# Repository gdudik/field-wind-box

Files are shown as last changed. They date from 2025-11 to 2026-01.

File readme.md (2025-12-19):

# Programming the main controller board (USB-PD controller setup)

I am using a cheapo CH134A programmer board with an alligator clamp for SOIC-8. Example: https://a.co/d/9YnwEmc. This unit needed to be modded per the included instructions to work with an EEPROM chip running at 3.3v.

Binary file `USB_C_PD_controller.bin` was built using the TI Application Customization Tool at https://www.ti.com/tool/USBCPD-APPLICATION-CUSTOMIZATION-TOOL.

Choices used:
- Device Type: TPS25751
- Choose TPS 25751S under _Are you a 5V @ 3A power source (provider) only?_
- Highest supported USB Speed: USB 2
- Preferred data role: Device/Upstream Facing Port
- Support BC 1.2? No
- Liquid detection on Type C Connector? No
- Vendor ID and Desired Product ID: TI Vendor ID/0x0000 Product ID

After downloading the bin file from the tool, I used IMS_Prog which is a tool for Mac that will interface with the CH134A. On PC there are other tools, but you'll have to Google. IMS_Prog supposedly also works on Linux.

# Wiring

## 4-Pin Header to XLR
| 4 Pin Header | Wire Color  | Function  | XLR Pin Num  |
|---|---|---|---|
| 1  | Red  | Wind Gauge +12v  | 2  |
|  2 | Black  | Wind Gauge Pwr GND  | Shell  |
| 3  | Green  | Data RX from WG  | 3  |
|  4 |  White | Data GND  | 1  |

## 3-Pin Header to LP16 for RS232
| 3 Pin Header | Wire Color  | Function  | LP16 Pin Num  |
|---|---|---|---|
| 1  | Orange  | RXI  | 2  |
|  2 | White  | Data GND  | 3  |
| 3  | Blue  | TXO  | 1  |

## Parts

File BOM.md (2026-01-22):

Case: Apache 1800 from HF https://www.harborfreight.com/1800-weatherproof-protective-case-small-black-64550.html $12.99
Battery: LiFePO4 12V 10AH ~$36.00
Charger: 12V 3A LiFePO4 charger ~18.00

Board $16
2x FT232RL $4.35 ea
XLR Port $4.91
Neutrik SCDF Plug $1.91
3-Pin CNLINKO serial port $7.33
USB-C CNLINKO port $5.06
USB-C CNLINKO cable $9.31
PowerCon port $5.24
Powercon plug $5.71
3.5" long 1/4-20 bolts qty 2 $.47 ea
1/4-20" nylock nuts qty 2 $.14 ea
Metal hold down strap $1.94
Hirose cable $7.50
standoffs x4 $.28 ea
o-rings for board mount x4 $.14
Right-angle USB cable $2.86
Orange power plug $4
Power button $8.38

3-wire harness for serial, 11"
4-wire harness for WG, 14"

battery board?
led caps

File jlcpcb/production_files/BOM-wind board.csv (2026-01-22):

Comment | Designator | Footprint | LCSC | Quantity
0 | R1 | R_0402_1005Metric | C17168 | 1
0.01uF | C51,C52,C53,C54 | C_0402_1005Metric | C15195 | 4
100K | R9 | R_0402_1005Metric | C25741 | 1
100nF | C11,C15,C16,C19,C20,C27,C31,C32,C35,C36,C41,C42,C50,C6,C8,C9 | C_0402_1005Metric | C1525 | 16
100uF / 10V | C57,C58 | C_1206_3216Metric | C7432784 | 2
10K | R10,R2,R8 | R_0402_1005Metric | C25744 | 3
10uF | C1,C25,C26,C3,C43,C44,C49 | C_0402_1005Metric | C15525 | 7
10uF / 10V | C55,C56 | C_0603_1608Metric | C19702 | 2
12MHz | Y1 | Crystal_SMD_3225-4Pin_3.2x2.5mm | C9002 | 1
1N4148WS | D5 | D_SOD-323 | C2128 | 1
1uF | C2,C45,C46 | C_0402_1005Metric | C52923 | 3
20K | R11 | R_0402_1005Metric | C25765 | 1
220K | R13 | R_0603_1608Metric | C22961 | 1
22uF | C28,C29,C30 | C_0603_1608Metric | C59461 | 3
30K | R12,R14 | R_0603_1608Metric | C22984 | 2
330pF | C47,C48 | C_0603_1608Metric | C1664 | 2
4.7uF | C33,C7 | C_0603_1608Metric | C19666 | 2
4.7uF | C17 | C_0402_1005Metric | C23733 | 1
4.7uF 25V | C24 | C_0805_2012Metric | C1779 | 1
470 | R18,R19,R3,R4,R5,R6,R7 | R_0402_1005Metric | C25117 | 7
470nF | C10,C12,C13,C18,C21,C22,C34,C37,C38 | C_0603_1608Metric | C1623 | 9
47pF | C14,C23,C39,C40 | C_0402_1005Metric | C1567 | 4
47pF | C4,C5 | C_0603_1608Metric | C1671 | 2
AONR21321 | Q1 | TRANS_AONR21321 | C541711 | 1
AT24C512C-SSHM | U10 | SOIC-8_3.9x4.9mm_P1.27mm | C54668 | 1
CH334R | U1 | QSOP-16_3.9x4.9mm_P0.635mm | C4154405 | 1
HCB3216KF-601T30 | FB1 | C_1206_3216Metric | C357023 | 1
LED | D15,D2,D4,D7 | LED_0603_1608Metric | C2286 | 4
LED | D1,D3,D8 | LED_0603_1608Metric | C2290 | 3
MMSZ18T1G | D6 | D_SOD-123 | C40707 | 1
PTPS25751SRSMR | U9 | RSM0032B-IPC_A | C22460852 | 1
SM15-02HTG | D10,D11,D12,D13,D14,D9 | SM0502HTG | C1975435 | 6
SPM6530T-2R2M | L1 | IND_SPM6530T-2R2M | C76855 | 1
TPS565242 | U6 | SOT6_DRL_TEX-L | C5219270 | 1
TVS2200DRV | U12 | WSON-6-1EP_2x2mm_P0.65mm_EP1x1.6mm | C523793 | 1
USB_C_Receptacle_USB2.0_14P | J1 | USB_C_Receptacle_HRO_TYPE-C-31-M-12 | C165948 | 1
XC6206PxxxMR | U11 | SOT-23-3 | C5446 | 1
ZT3222F | U4,U5,U8 | TSSOP-20_4.4x6.5mm_P0.65mm | C19078605 | 3

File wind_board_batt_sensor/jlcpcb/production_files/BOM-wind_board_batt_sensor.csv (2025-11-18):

Comment | Designator | Footprint | LCSC | Quantity
30 | R6 | R_0805_2012Metric_Pad1.20x1.40mm_HandSolder |  | 1
10K | R9 | R_0805_2012Metric_Pad1.20x1.40mm_HandSolder |  | 1
100nF | C5 | R_0805_2012Metric_Pad1.20x1.40mm_HandSolder |  | 1
PTSM82903SISB2R | U2 | SIS0011A-MFG |  | 1
TestPoint | J_PA0 | TestPoint_Pad_4.0x4.0mm |  | 1
Batt + | J1 | MountingHole_4.3mm_M4_ISO7380_Pad_TopBottom |  | 1
26.1k | R3 | R_0805_2012Metric_Pad1.20x1.40mm_HandSolder |  | 1
LED | D5 | LED_D5.0mm |  | 1
LED | D2 | LED_D5.0mm |  | 1
LED | D1 | LED_D5.0mm |  | 1
Batt - | J2 | MountingHole_4.3mm_M4_ISO7380_Pad_TopBottom |  | 1
30 | R4 | R_0805_2012Metric_Pad1.20x1.40mm_HandSolder |  | 1
MAX17263xxTE | U1 | DFN-14-1EP_3x3mm_P0.4mm_EP1.78x2.35mm |  | 1
22uF | C2 | R_0805_2012Metric_Pad1.20x1.40mm_HandSolder |  | 1
200k - 0.1% | R2 | R_0805_2012Metric_Pad1.20x1.40mm_HandSolder |  | 1
10uF | C1 | R_0805_2012Metric_Pad1.20x1.40mm_HandSolder |  | 1
4.7uF | C6 | R_0805_2012Metric_Pad1.20x1.40mm_HandSolder |  | 1
100 nF | C3 | R_0805_2012Metric_Pad1.20x1.40mm_HandSolder |  | 1
LED | D4 | LED_D5.0mm |  | 1
30 | R5 | R_0805_2012Metric_Pad1.20x1.40mm_HandSolder |  | 1
LED | D3 | LED_D5.0mm |  | 1
10K | R11 | R_0805_2012Metric_Pad1.20x1.40mm_HandSolder |  | 1
30 | R7 | R_0805_2012Metric_Pad1.20x1.40mm_HandSolder |  | 1
10K | R10 | R_0805_2012Metric_Pad1.20x1.40mm_HandSolder |  | 1
470nF | C4 | R_0805_2012Metric_Pad1.20x1.40mm_HandSolder |  | 1
1.5M - 0.1% | R1 | R_0805_2012Metric_Pad1.20x1.40mm_HandSolder |  | 1
ATtiny402-SS | U3 | SOIC-8_3.9x4.9mm_P1.27mm |  | 1
Sys - | J4 | MountingHole_4.3mm_M4_ISO7380_Pad_TopBottom |  | 1
300k - 0.1% | R8 | R_0805_2012Metric_Pad1.20x1.40mm_HandSolder |  | 1
Sys + | J3 | MountingHole_4.3mm_M4_ISO7380_Pad_TopBottom |  | 1

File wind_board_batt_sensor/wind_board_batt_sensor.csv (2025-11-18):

Reference | Qty | Value | DNP | Exclude from BOM | Exclude from Board | Footprint | Datasheet
C1 | 1 | 10uF |  |  |  | Resistor_SMD:R_0805_2012Metric_Pad1.20x1.40mm_HandSolder | ~
C2 | 1 | 22uF |  |  |  | Resistor_SMD:R_0805_2012Metric_Pad1.20x1.40mm_HandSolder | ~
C3 | 1 | 100 nF |  |  |  | Resistor_SMD:R_0805_2012Metric_Pad1.20x1.40mm_HandSolder | ~
C4 | 1 | 470nF |  |  |  | Resistor_SMD:R_0805_2012Metric_Pad1.20x1.40mm_HandSolder | ~
C5 | 1 | 100nF |  |  |  | Resistor_SMD:R_0805_2012Metric_Pad1.20x1.40mm_HandSolder | ~
C6 | 1 | 4.7uF |  |  |  | Resistor_SMD:R_0805_2012Metric_Pad1.20x1.40mm_HandSolder | ~
D1,D2,D3,D4,D5 | 5 | LED |  |  |  | LED_THT:LED_D5.0mm | ~
J1 | 1 | Batt + |  |  |  | MountingHole:MountingHole_4.3mm_M4_ISO7380_Pad_TopBottom | ~
J2 | 1 | Batt - |  |  |  | MountingHole:MountingHole_4.3mm_M4_ISO7380_Pad_TopBottom | ~
J3 | 1 | Sys + |  |  |  | MountingHole:MountingHole_4.3mm_M4_ISO7380_Pad_TopBottom | ~
J4 | 1 | Sys - |  |  |  | MountingHole:MountingHole_4.3mm_M4_ISO7380_Pad_TopBottom | ~
J_PA0 | 1 | TestPoint |  |  |  | TestPoint:TestPoint_Pad_4.0x4.0mm | ~
R1 | 1 | 1.5M - 0.1% |  |  |  | Resistor_SMD:R_0805_2012Metric_Pad1.20x1.40mm_HandSolder | ~
R2 | 1 | 200k - 0.1% |  |  |  | Resistor_SMD:R_0805_2012Metric_Pad1.20x1.40mm_HandSolder | ~
R3 | 1 | 26.1k |  |  |  | Resistor_SMD:R_0805_2012Metric_Pad1.20x1.40mm_HandSolder | ~
R4,R5,R6,R7 | 4 | 30 |  |  |  | Resistor_SMD:R_0805_2012Metric_Pad1.20x1.40mm_HandSolder | ~
R8 | 1 | 300k - 0.1% |  |  |  | Resistor_SMD:R_0805_2012Metric_Pad1.20x1.40mm_HandSolder | ~
R9,R10,R11 | 3 | 10K |  |  |  | Resistor_SMD:R_0805_2012Metric_Pad1.20x1.40mm_HandSolder | ~
R_SENSE3 | 1 | 10m |  |  |  | Resistor_SMD:R_1206_3216Metric_Pad1.30x1.75mm_HandSolder | ~
U1 | 1 | MAX17263xxTE |  |  |  | Package_DFN_QFN:DFN-14-1EP_3x3mm_P0.4mm_EP1.78x2.35mm | https://datasheets.maximintegrated.com/en/ds/MAX17263.pdf
U2 | 1 | PTSM82903SISB2R |  |  |  | TPSM82903:SIS0011A-MFG | PTSM82903SISB2R
U3 | 1 | ATtiny402-SS |  |  |  | Package_SO:SOIC-8_3.9x4.9mm_P1.27mm | http://ww1.microchip.com/downloads/en/DeviceDoc/ATtiny202-402-AVR-MCU-with-Core-Independent-Peripherals_and-picoPower-40001969A.pdf

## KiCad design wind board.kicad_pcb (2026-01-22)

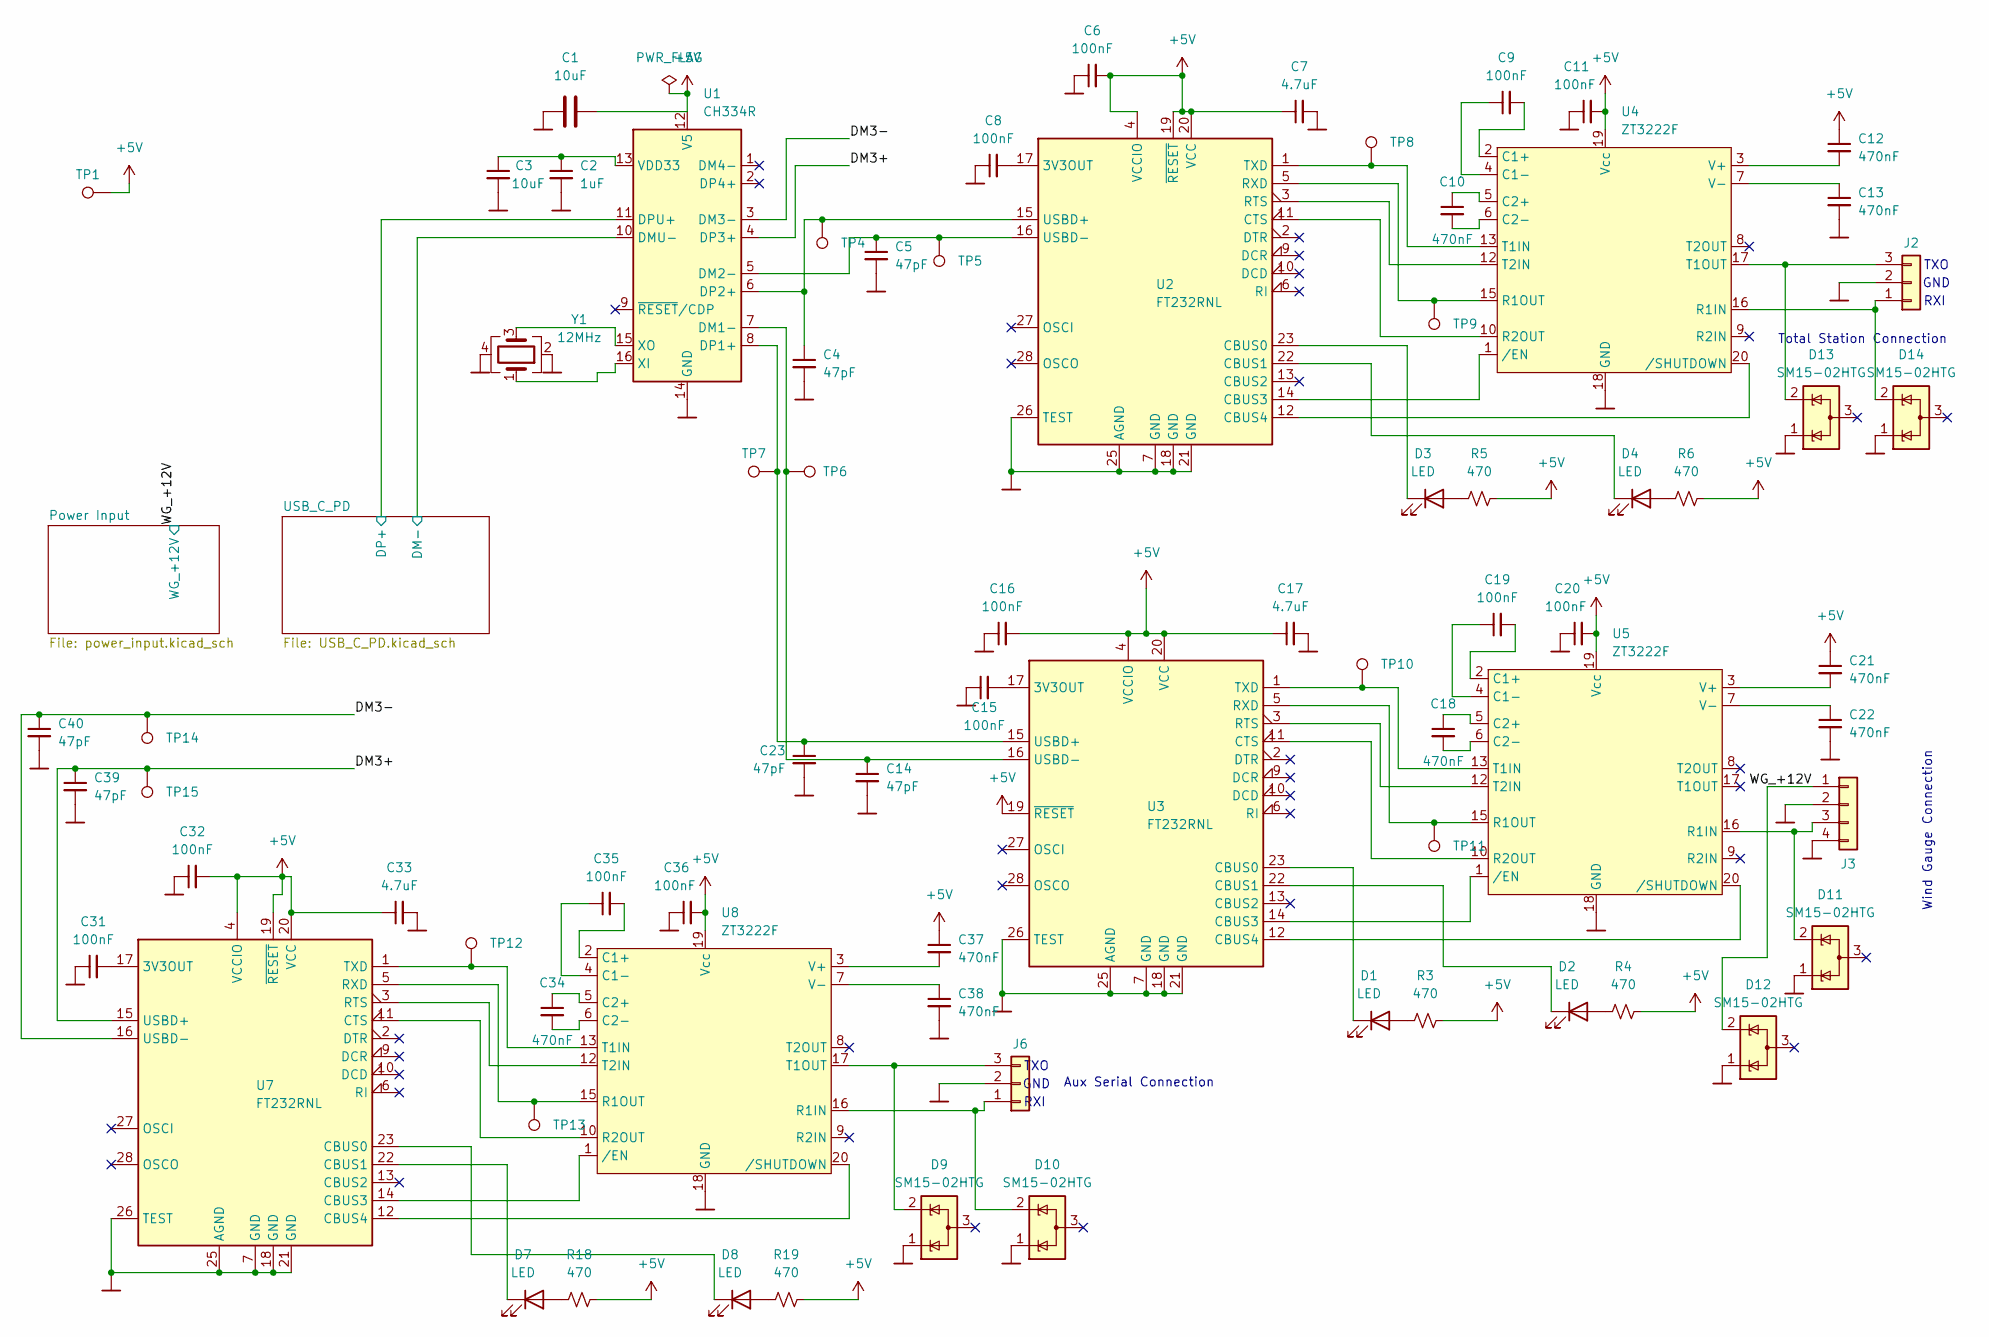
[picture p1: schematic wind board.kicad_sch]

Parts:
C1, C3: 10uF; C_0402_1005Metric
C2: 1uF; C_0402_1005Metric
C4, C5: 47pF; C_0603_1608Metric
C6, C8, C9, C11, C15, C16, C19, C20, C31, C32, C35, C36: 100nF; C_0402_1005Metric
C7, C33: 4.7uF; C_0603_1608Metric
C10, C12, C13, C18, C21, C22, C34, C37, C38: 470nF; C_0603_1608Metric
C14, C23, C39, C40: 47pF; C_0402_1005Metric
C17: 4.7uF; C_0402_1005Metric
D1, D2, D3, D4, D7, D8: LED; LED_0603_1608Metric
D9, D10, D11, D12, D13, D14: SM15-02HTG; SM0502HTG
J2, J6: Conn_01x06_MountingPin; PinHeader_1x03_P2.54mm_Horizontal
J3: Conn_01x06_MountingPin; PinHeader_1x04_P2.54mm_Horizontal
R3, R4, R5, R6, R18, R19: 470; R_0402_1005Metric
TP1, TP4, TP5, TP6, TP7, TP8, TP9, TP10, TP11, TP12, TP13, TP14, TP15: TestPoint; TestPoint_THTPad_1.0x1.0mm_Drill0.5mm
U1: CH334R; QSOP-16_3.9x4.9mm_P0.635mm
U2, U3, U7: FT232RNL; SSOP-28_5.3x10.2mm_P0.65mm
U4, U5, U8: ZT3222F; TSSOP-20_4.4x6.5mm_P0.65mm
Y1: 12MHz; Crystal_SMD_3225-4Pin_3.2x2.5mm

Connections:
+5V: C1.2, C6.2, C7.1, C11.2, C12.1, C16.2, C17.1, C20.2, C21.1, C32.2, C33.1, C36.2, C37.1, R3.2, R4.2, R5.2, R6.2, R18.2, R19.2, TP1.1, U1.12 (V5), U2.4 (VCCIO), U2.19 (~RESET), U2.20 (VCC), U3.4 (VCCIO), U3.19 (~RESET), U3.20 (VCC), U4.19 (Vcc), U5.19 (Vcc), U7.4 (VCCIO), U7.19 (~RESET), U7.20 (VCC), U8.19 (Vcc); also elsewhere on the board
/DM3+: C39.1, TP15.1, U1.4 (DP3+), U7.15 (USBD+)
/DM3-: C40.1, TP14.1, U1.3 (DM3-), U7.16 (USBD-)
/USB_C_PD/DM-: U1.10 (DMU-); also elsewhere on the board
/USB_C_PD/DP+: U1.11 (DPU+); also elsewhere on the board
/WG_+12V: D12.2 (K), J3.1; also elsewhere on the board
unnamed: D1.2 (A), R3.1
unnamed: D1.1 (K), U3.23 (CBUS0)
unnamed: D2.2 (A), R4.1
unnamed: D2.1 (K), U3.22 (CBUS1)
unnamed: D3.2 (A), R5.1
unnamed: D3.1 (K), U2.23 (CBUS0)
unnamed: D4.2 (A), R6.1
unnamed: D4.1 (K), U2.22 (CBUS1)
unnamed: D7.2 (A), R18.1
unnamed: D7.1 (K), U7.22 (CBUS1)
unnamed: D8.2 (A), R19.1
unnamed: D8.1 (K), U7.23 (CBUS0)
unnamed: D14.2 (K), J2.1, U4.16 (R1IN)
unnamed: D13.2 (K), J2.3, U4.17 (T1OUT)
unnamed: D11.2 (K), J3.3, U5.16 (R1IN)
unnamed: D10.2 (K), J6.1, U8.16 (R1IN)
unnamed: D9.2 (K), J6.3, U8.17 (T1OUT)
unnamed: C14.1, TP6.1, U1.7 (DM1-), U3.16 (USBD-)
unnamed: C5.1, TP5.1, U1.5 (DM2-), U2.16 (USBD-)
unnamed: C23.1, TP7.1, U1.8 (DP1+), U3.15 (USBD+)
unnamed: C4.1, TP4.1, U1.6 (DP2+), U2.15 (USBD+)
unnamed: C2.1, C3.1, U1.13 (VDD33)
unnamed: U1.16 (XI), Y1.1
unnamed: U1.15 (XO), Y1.3
unnamed: C8.2, U2.17 (3V3OUT)
unnamed: U2.14 (CBUS3), U4.1 (/EN)
unnamed: U2.12 (CBUS4), U4.20 (/SHUTDOWN)
unnamed: U2.11 (CTS), U4.10 (R2OUT)
unnamed: U2.3 (RTS), U4.12 (T2IN)
unnamed: TP9.1, U2.5 (RXD), U4.15 (R1OUT)
unnamed: TP8.1, U2.1 (TXD), U4.13 (T1IN)
unnamed: C15.2, U3.17 (3V3OUT)
unnamed: U3.14 (CBUS3), U5.1 (/EN)
unnamed: U3.12 (CBUS4), U5.20 (/SHUTDOWN)
unnamed: U3.11 (CTS), U5.10 (R2OUT)
unnamed: U3.3 (RTS), U5.12 (T2IN)
unnamed: TP11.1, U3.5 (RXD), U5.15 (R1OUT)
unnamed: TP10.1, U3.1 (TXD), U5.13 (T1IN)
unnamed: C9.2, U4.2 (C1+)
unnamed: C9.1, U4.4 (C1-)
unnamed: C10.1, U4.5 (C2+)
unnamed: C10.2, U4.6 (C2-)
unnamed: C12.2, U4.3 (V+)
unnamed: C13.1, U4.7 (V-)
unnamed: C19.2, U5.2 (C1+)
unnamed: C19.1, U5.4 (C1-)
unnamed: C18.1, U5.5 (C2+)
unnamed: C18.2, U5.6 (C2-)
unnamed: C21.2, U5.3 (V+)
unnamed: C22.1, U5.7 (V-)
unnamed: C31.2, U7.17 (3V3OUT)
unnamed: U7.14 (CBUS3), U8.1 (/EN)
unnamed: U7.12 (CBUS4), U8.20 (/SHUTDOWN)
unnamed: U7.11 (CTS), U8.10 (R2OUT)
unnamed: U7.3 (RTS), U8.12 (T2IN)
unnamed: TP13.1, U7.5 (RXD), U8.15 (R1OUT)
unnamed: TP12.1, U7.1 (TXD), U8.13 (T1IN)
unnamed: C35.2, U8.2 (C1+)
unnamed: C35.1, U8.4 (C1-)
unnamed: C34.1, U8.5 (C2+)
unnamed: C34.2, U8.6 (C2-)
unnamed: C37.2, U8.3 (V+)
unnamed: C38.1, U8.7 (V-)
~: C1.1, C2.2, C3.2, C4.2, C5.2, C6.1, C7.2, C8.1, C11.1, C13.2, C14.2, C15.1, C16.1, C17.2, C20.1, C22.2, C23.2, C31.1, C32.1, C33.2, C36.1, C38.2, C39.2, C40.2, D9.1 (K), D10.1 (K), D11.1 (K), D12.1 (K), D13.1 (K), D14.1 (K), J2.2, J3.2, J3.4, J6.2, U1.14 (GND), U2.7 (GND), U2.18 (GND), U2.21 (GND), U2.25 (AGND), U2.26 (TEST), U3.7 (GND), U3.18 (GND), U3.21 (GND), U3.25 (AGND), U3.26 (TEST), U4.18 (GND), U5.18 (GND), U7.7 (GND), U7.18 (GND), U7.21 (GND), U7.25 (AGND), U7.26 (TEST), U8.18 (GND), Y1.2, Y1.4; also elsewhere on the board

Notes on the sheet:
Total Station Connection
Aux Serial Connection
GND
TXO
Wind Gauge Connection
RXI

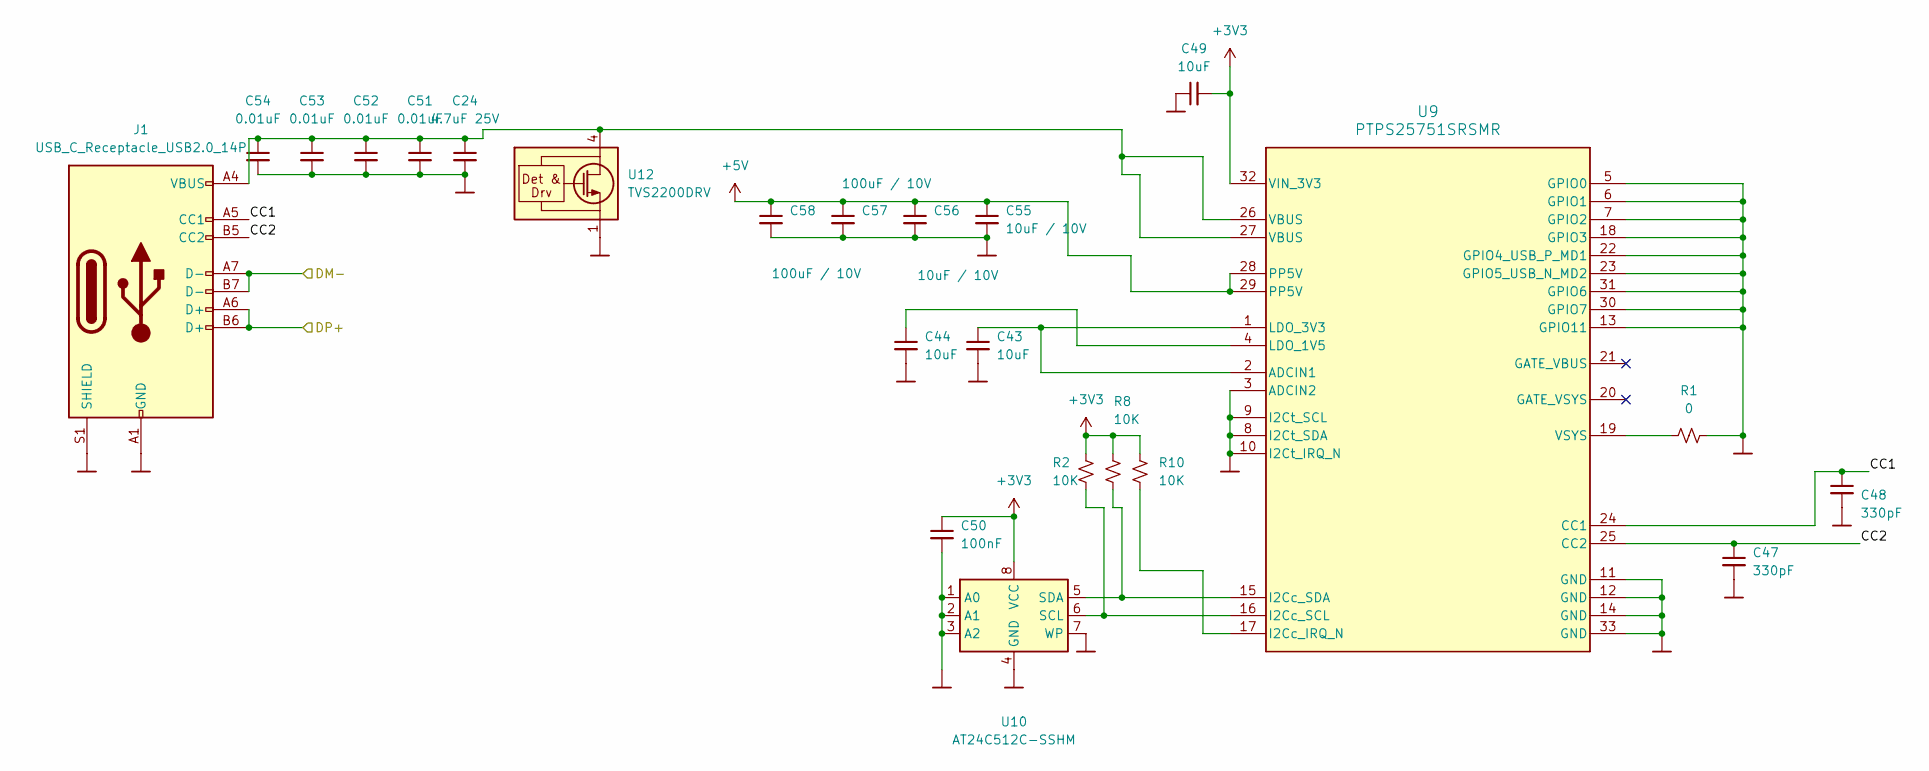
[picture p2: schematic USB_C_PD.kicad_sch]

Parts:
C24: 4.7uF 25V; C_0805_2012Metric
C43, C44, C49: 10uF; C_0402_1005Metric
C47, C48: 330pF; C_0603_1608Metric
C50: 100nF; C_0402_1005Metric
C51, C52, C53, C54: 0.01uF; C_0402_1005Metric
C55, C56: 10uF / 10V; C_0603_1608Metric
C57, C58: 100uF / 10V; C_1206_3216Metric
J1: USB_C_Receptacle_USB2.0_14P; USB_C_Receptacle_HRO_TYPE-C-31-M-12
R1: 0; R_0402_1005Metric
R2, R8, R10: 10K; R_0402_1005Metric
U9: PTPS25751SRSMR; RSM0032B-IPC_A
U10: AT24C512C-SSHM; SOIC-8_3.9x4.9mm_P1.27mm
U12: TVS2200DRV; WSON-6-1EP_2x2mm_P0.65mm_EP1x1.6mm

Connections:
+3V3: C49.2, C50.1, R2.1, R8.1, R10.1, U9.32 (VIN_3V3), U10.8 (VCC); also elsewhere on the board
+5V: C55.1, C56.1, C57.1, C58.1, U9.28 (PP5V), U9.29 (PP5V); also elsewhere on the board
/USB_C_PD/CC1: C48.1, J1.A5 (CC1), U9.24 (CC1)
/USB_C_PD/CC2: C47.1, J1.B5 (CC2), U9.25 (CC2)
/USB_C_PD/DM-: J1.A7 (D-), J1.B7 (D-); also elsewhere on the board
/USB_C_PD/DP+: J1.A6 (D+), J1.B6 (D+); also elsewhere on the board
unnamed: C24.1, C51.1, C52.1, C53.1, C54.1, J1.A4 (VBUS), J1.A9 (VBUS), J1.B4 (VBUS), J1.B9 (VBUS), U9.26 (VBUS), U9.27 (VBUS), U12.4 (IN), U12.5 (IN), U12.6 (IN)
unnamed: C43.1, U9.1 (LDO_3V3), U9.2 (ADCIN1)
unnamed: R10.2, U9.17 (I2Cc_IRQ_N)
unnamed: C44.1, U9.4 (LDO_1V5)
unnamed: R1.2, U9.19 (VSYS)
unnamed: R2.2, U9.16 (I2Cc_SCL), U10.6 (SCL)
unnamed: R8.2, U9.15 (I2Cc_SDA), U10.5 (SDA)
~: C24.2, C43.2, C44.2, C47.2, C48.2, C49.1, C50.2, C51.2, C52.2, C53.2, C54.2, C55.2, C56.2, C57.2, C58.2, J1.A1 (GND), J1.A12 (GND), J1.B1 (GND), J1.B12 (GND), J1.S1 (SHIELD), R1.1, U9.3 (ADCIN2), U9.5 (GPIO0), U9.6 (GPIO1), U9.7 (GPIO2), U9.8 (I2Ct_SDA), U9.9 (I2Ct_SCL), U9.10 (I2Ct_IRQ_N), U9.11 (GND), U9.12 (GND), U9.13 (GPIO11), U9.14 (GND), U9.18 (GPIO3), U9.22 (GPIO4_USB_P_MD1), U9.23 (GPIO5_USB_N_MD2), U9.30 (GPIO7), U9.31 (GPIO6), U9.33 (GND), U10.1 (A0), U10.2 (A1), U10.3 (A2), U10.4 (GND), U10.7 (WP), U12.1 (GND), U12.2 (GND), U12.3 (GND), U12.7 (GND); also elsewhere on the board

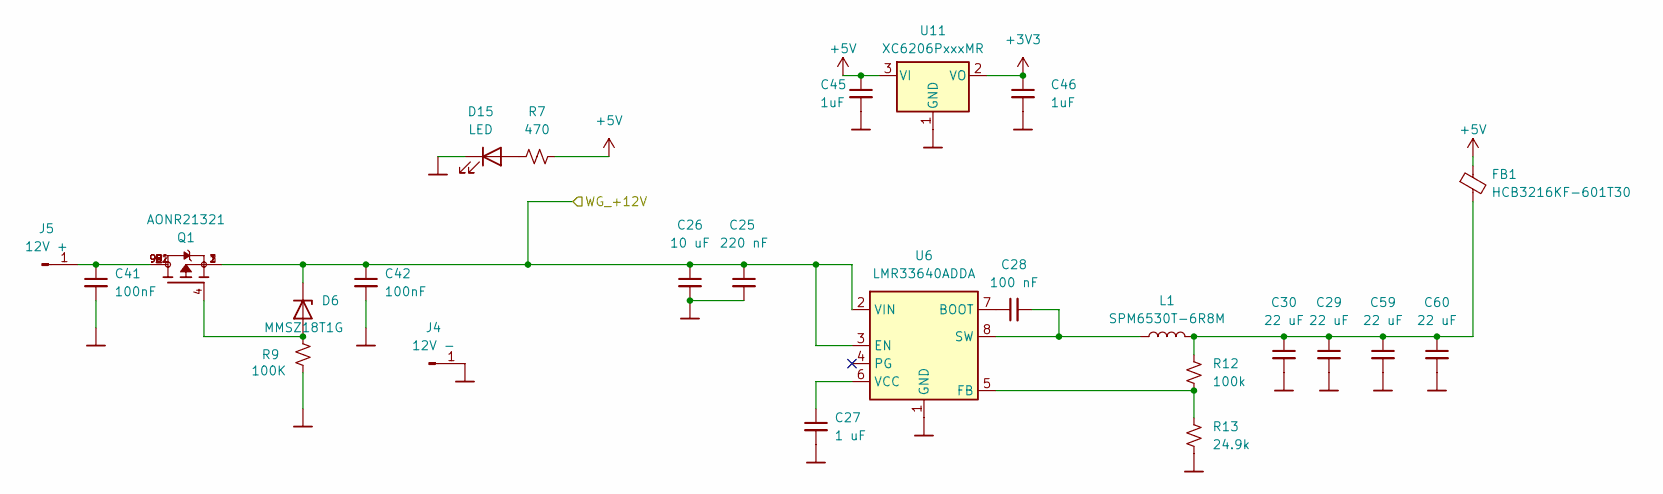
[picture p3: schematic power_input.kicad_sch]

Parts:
C25: 220 nF; C_0402_1005Metric
C26: 10 uF; C_0402_1005Metric
C27: 1 uF; C_0402_1005Metric
C28: 100 nF; C_0402_1005Metric
C29, C30, C59, C60: 22 uF; C_0402_1005Metric
C41, C42: 100nF; C_0402_1005Metric
C45, C46: 1uF; C_0402_1005Metric
D6: MMSZ18T1G; D_SOD-123
D15: LED; LED_0603_1608Metric
FB1: HCB3216KF-601T30; C_1206_3216Metric
J4: 12V -; MountingHole_4.3mm_M4_ISO7380_Pad_TopBottom
J5: 12V +; MountingHole_4.3mm_M4_ISO7380_Pad_TopBottom
L1: SPM6530T-6R8M; IND_SPM6530T-2R2M
Q1: AONR21321; TRANS_AONR21321; PARTREV 1.0
R7: 470; R_0402_1005Metric
R9: 100K; R_0402_1005Metric
R12: 100k; C_0402_1005Metric
R13: 24.9k; R_0402_1005Metric
U6: LMR33640ADDA; Texas_HSOP-8-1EP_3.9x4.9mm_P1.27mm_ThermalVias
U11: XC6206PxxxMR; SOT-23-3

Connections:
+3V3: C46.1, U11.2 (VO); also elsewhere on the board
+5V: C45.1, FB1.1, R7.2, U11.3 (VI); also elsewhere on the board
/WG_+12V: C25.1, C26.1, C42.1, D6.1 (K), Q1.1, Q1.2, Q1.3, U6.2 (VIN), U6.3 (EN); also elsewhere on the board
unnamed: C29.1, C30.1, C59.1, C60.1, FB1.2, L1.2, R12.1
unnamed: D6.2 (A), Q1.4, R9.2
unnamed: D15.2 (A), R7.1
unnamed: C41.1, J5.1, Q1.5, Q1.6, Q1.7, Q1.8, Q1.9, Q1.9_1, Q1.9_2
unnamed: C28.1, U6.7 (BOOT)
unnamed: R12.2, R13.1, U6.5 (FB)
unnamed: C28.2, L1.1, U6.8 (SW)
unnamed: C27.1, U6.6 (VCC)
~: C25.2, C26.2, C27.2, C29.2, C30.2, C41.2, C42.2, C45.2, C46.2, C59.2, C60.2, D15.1 (K), J4.1, R9.1, R13.2, U6.1 (GND), U6.9 (GND), U11.1 (GND); also elsewhere on the board

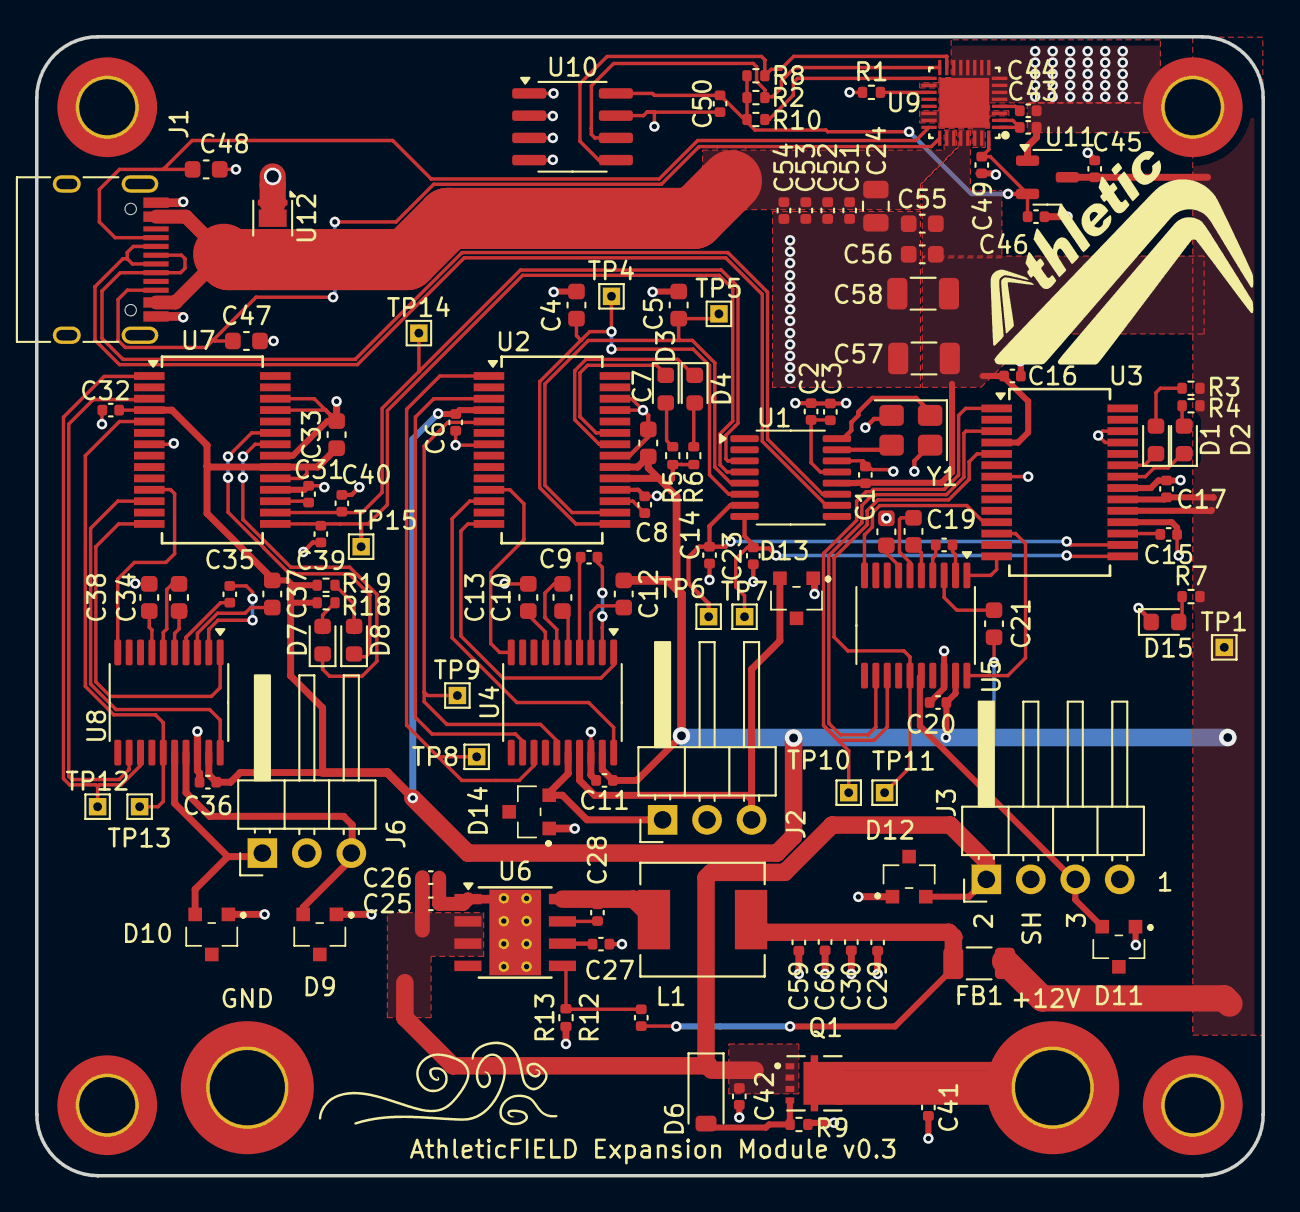
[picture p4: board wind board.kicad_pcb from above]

Board: 2 copper layers, 70.1 x 65.1 mm, 123 parts (0 on the bottom side), 88 nets.

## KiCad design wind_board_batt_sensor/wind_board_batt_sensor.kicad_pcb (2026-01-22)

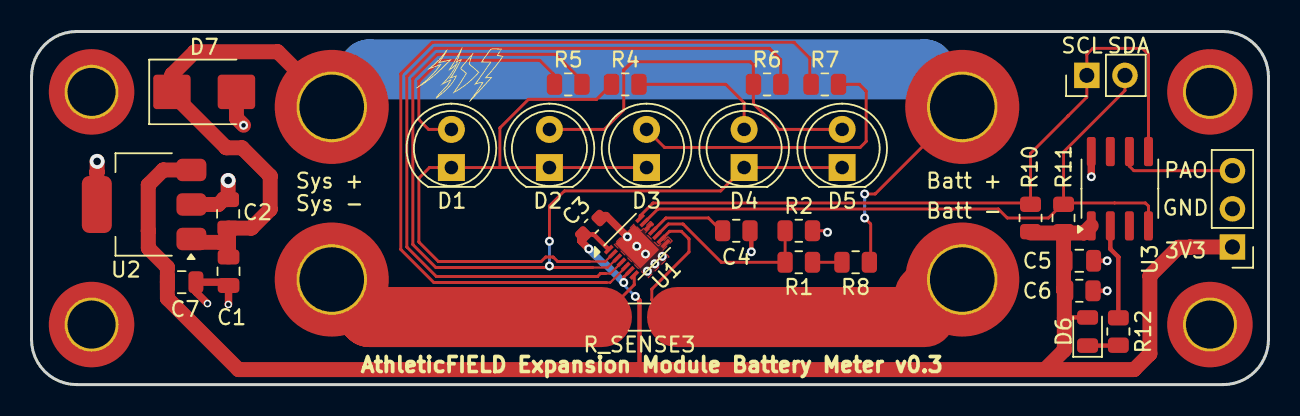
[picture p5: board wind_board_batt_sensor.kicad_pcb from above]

Board: 2 copper layers, 82.4 x 23.5 mm, 34 parts (0 on the bottom side), 20 nets.

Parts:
C1: 10uF; C_0805_2012Metric
C2, C5: 100nF; C_0805_2012Metric
C3: 100nF; C_0603_1608Metric
C4: 470nF; R_0805_2012Metric
C6: 4.7uF; R_0805_2012Metric
C7: 22uF; C_0805_2012Metric
D1, D2, D3, D4, D5: LED; LED_D5.0mm
D6: LED; LED_0805_2012Metric
D7: SMBJ18A; D_SMB
J1: Batt +; MountingHole_4.3mm_M4_ISO7380_Pad_TopBottom
J2: Batt -; MountingHole_4.3mm_M4_ISO7380_Pad_TopBottom
J3: Sys +; MountingHole_4.3mm_M4_ISO7380_Pad_TopBottom
J4: Sys -; MountingHole_4.3mm_M4_ISO7380_Pad_TopBottom
J5: Conn_01x03_Socket; PinHeader_1x03_P2.54mm_Vertical
J6: Conn_01x02_Socket; PinHeader_1x02_P2.54mm_Vertical
R1: 1.5M - 0.1%; R_0805_2012Metric
R2: 200k - 0.1%; R_0805_2012Metric
R4, R5, R6, R7: 30; R_0805_2012Metric
R8: 300k - 0.1%; R_0805_2012Metric
R10, R11: 10K; R_0805_2012Metric
R12: 150; R_0805_2012Metric
R_SENSE3: 10m; R_1206_3216Metric
U1: MAX17263xxTE; DFN-14-1EP_3x3mm_P0.4mm_EP1.78x2.35mm
U2: TLE42744GS V33; SOT-223
U3: ATtiny402-SS; SOIC-8_3.9x4.9mm_P1.27mm

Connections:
+3.3V: C3.1, C5.2, C6.1, C7.1, D6.2 (A), J5.1, R10.1, R11.1, U1.1 (TH), U1.6 (BATT), U2.3 (Q), U3.1 (VCC)
+12V: C1.1, C2.1, D7.1 (K), J1.1, J3.1, R8.1, U2.1 (I)
unnamed: D1.2 (A), R5.1
unnamed: D1.1 (K), D2.1 (K), D3.1 (K), R4.2, U1.2 (L1)
unnamed: D2.2 (A), D5.2 (A), R6.1
unnamed: D3.2 (A), R7.1
unnamed: D4.2 (A), R4.1
unnamed: D4.1 (K), D5.1 (K), R5.2, U1.3 (L2)
unnamed: D6.1 (K), R12.1
unnamed: J4.1, R_SENSE3.2, U1.7 (CSN)
unnamed: J5.3, U3.6 (~RESET/PA0)
unnamed: J6.1, R10.2, U1.14 (SCL), U3.5 (PA2)
unnamed: J6.2, R11.2, U1.13 (SDA), U3.4 (PA1)
unnamed: R1.1, R8.2
unnamed: R1.2, R2.1, U1.10 (CELLX/CSPH)
unnamed: R6.2, U1.4 (L3)
unnamed: R7.2, U1.5 (L4)
unnamed: C4.1, U1.11 (REG)
unnamed: R12.2, U3.2 (PA6)
~: C1.2, C2.2, C3.2, C4.2, C5.1, C6.2, C7.2, D7.2 (A), J2.1, J5.2, R2.2, R_SENSE3.1, U1.8 (GND), U1.9 (CSPL), U1.12 (ALRT), U1.15 (EP), U2.2 (GND), U2.4 (GND), U3.8 (GND)

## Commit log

2025-09-30 added 3rd interface, tvs diodes, charging circuit
    [power_input.kicad_sch, wind board.kicad_pcb, wind board.kicad_sch]
2025-09-30 through hole test points
    [wind board.kicad_pcb]
2025-10-16 starting pd chip
    [USB_C_PD.kicad_sch, power_input.kicad_sch, wind board.kicad_pcb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]
2025-10-16 added footprints, minor deletions
    [USB_C_PD.kicad_sch, power_input.kicad_sch]
2025-10-17 add usb-c-pd routing
    [USB_C_PD.kicad_sch, power_input.kicad_sch, wind board.kicad_pcb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]
2025-10-17 update capacitors
    [wind board.kicad_pcb]
2025-10-20 add fuel gauge
    [wind_board_batt_sensor.kicad_pcb, wind_board_batt_sensor.kicad_sch]
2025-10-20 dave's changes
    [USB_C_PD.kicad_sch]
2025-10-21 All components to 0805 on battery board
    [wind_board_batt_sensor.kicad_pcb, wind_board_batt_sensor.kicad_sch]
2025-10-21 add vias
    [wind_board_batt_sensor.kicad_pcb]
2025-10-22 add silliness
    [wind_board_batt_sensor.kicad_pcb]
2025-11-03 swap sda-scl pins
    [wind_board_batt_sensor.kicad_pcb, wind_board_batt_sensor.kicad_sch]
2025-11-04 add led and sca-scl header
    [wind_board_batt_sensor.kicad_pcb, wind_board_batt_sensor.kicad_sch]
2025-11-04 fix stuff
    [wind_board_batt_sensor.kicad_pcb, wind_board_batt_sensor.kicad_sch]
2025-11-04 moar fixes
    [wind_board_batt_sensor.kicad_pcb]
2025-11-18 update bom
    [BOM-wind board.csv, BOM-wind_board_batt_sensor.csv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]
2025-12-13 new power supply
    [wind_board_batt_sensor.kicad_pcb, wind_board_batt_sensor.kicad_sch]
2025-12-15 add new power supply
    [wind_board_batt_sensor.kicad_pcb, wind_board_batt_sensor.kicad_sch]
2025-12-16 new regulator
    [wind_board_batt_sensor.kicad_pcb, wind_board_batt_sensor.kicad_sch]
2025-12-16 update layout around PSU
    [wind_board_batt_sensor.kicad_pcb]
2026-01-22 new buck
    [power_input.kicad_sch, wind board.kicad_pcb]
2026-01-22 remove pullup resistor
    [power_input.kicad_sch, wind board.kicad_pcb]
